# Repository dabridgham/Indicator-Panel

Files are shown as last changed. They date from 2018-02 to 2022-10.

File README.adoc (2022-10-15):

= Indicator Panel

Here we replicate the functionality of DEC's indicator panels used on
PDP-11s and some other machines.  It was designed in conjunction with
the http://github.com/dabridgham/QSIC[QSIC project] to build a QBUS
board to emulate the old DEC disk drives using more modern storage
technology and we wanted to have blinkenlights to go with.

indicator-panel*:: KiCad design for the indicator panel circuit boards
   themselves.  Three boards make a full indicator panel.

adapter*:: A small adapter board to convert from the version 1 pinout
   to version 2.

inlay*:: Various inlay designs we've come up with to use with the
   QSIC.
   * inlay-qbus: QBUS monitor.
   * inlay-rk11-c: Our idea of what the RK11-C indicator panel might
     have looked like.
   * inlay-rk11-f: Used for both the RK11-F and the RP11-D, the new
      controllers we've created for the QSIC.
   * inlay-rp11: The RP11 indicator panel rendered here.
   * inlay-unibus: Unibus monitor.

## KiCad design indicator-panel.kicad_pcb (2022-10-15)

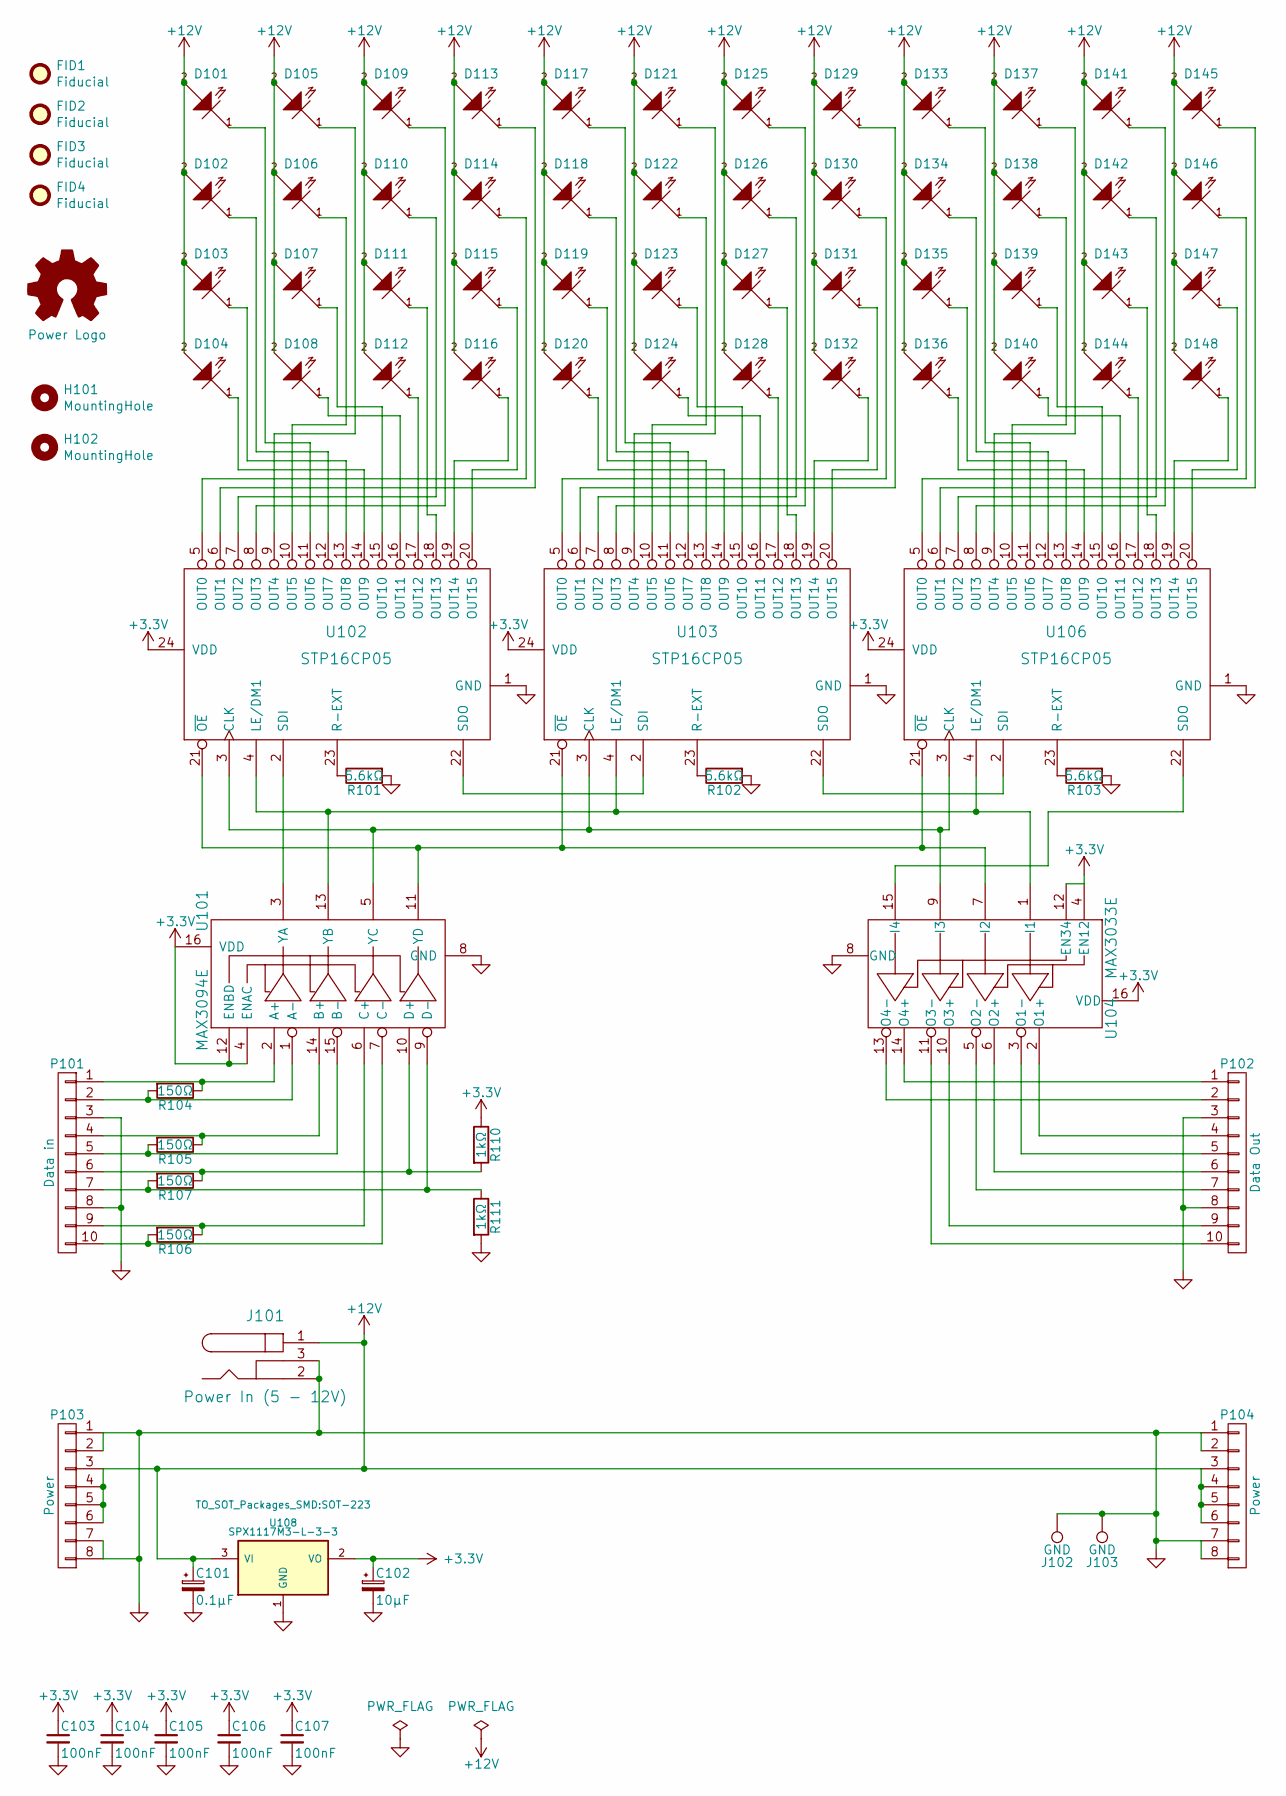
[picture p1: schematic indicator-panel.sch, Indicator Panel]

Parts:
C101: 0.1μF; CP_Tantalum_Case-R_EIA-2012-12_Reflow
C102: 10μF; CP_Tantalum_Case-R_EIA-2012-12_Wave
C103, C104, C105, C106, C107: 100nF; C_0805
D101, D102, D103, D104, D105, D106, D107, D108, D109, D110, D111, D112, D113, D114, D115, D116, D117, D118, D119, D120, D121, D122, D123, D124, D125, D126, D127, D128, D129, D130, D131, D132, D133, D134, D135, D136, D137, D138, D139, D140, D141, D142, D143, D144, D145, D146, D147, D148: LED-45; LED-0805
FID1, FID2, FID3, FID4: Fiducial; Fiducial_1mm_Mask2mm
H101, H102: MountingHole; MountingHole_3.5mm
J101: Power In (5 - 12V); PJ-032B
J102, J103: GND; MountingHole_3-5mm
P101: Data in; Pin_Header_Angled_2x05
P102: Data Out; Socket_Strip_Angled_2x05
P103: Power; Pin_Header_Angled_2x04
P104: Power; Socket_Strip_Angled_2x04
PowerLogo1: Power Logo; Barrel
R101, R102, R103: 5.6kΩ; R_0805
R104, R105, R106, R107: 150Ω; R_0805
R110, R111: 1kΩ; R_0805
U101: MAX3094E; SOIC-16_3.9x9.9mm_Pitch1.27mm
U102, U103, U106: STP16CP05; SOIC-24_7.5x15.4mm_Pitch1.27mm
U104: MAX3033E; SOIC-16_3.9x9.9mm_Pitch1.27mm
U108: SPX1117M3-L-3-3; SOT-223

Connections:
+3V3: C102.1, C103.1, C104.1, C105.1, C106.1, C107.1, R110.1, U101.4 (ENAC), U101.12 (ENBD), U101.16 (VDD), U102.24 (VDD), U103.24 (VDD), U104.4 (EN12), U104.12 (EN34), U104.16 (VDD), U106.24 (VDD), U108.2 (VO)
+12V: C101.1, D101.2 (A), D102.2 (A), D103.2 (A), D104.2 (A), D105.2 (A), D106.2 (A), D107.2 (A), D108.2 (A), D109.2 (A), D110.2 (A), D111.2 (A), D112.2 (A), D113.2 (A), D114.2 (A), D115.2 (A), D116.2 (A), D117.2 (A), D118.2 (A), D119.2 (A), D120.2 (A), D121.2 (A), D122.2 (A), D123.2 (A), D124.2 (A), D125.2 (A), D126.2 (A), D127.2 (A), D128.2 (A), D129.2 (A), D130.2 (A), D131.2 (A), D132.2 (A), D133.2 (A), D134.2 (A), D135.2 (A), D136.2 (A), D137.2 (A), D138.2 (A), D139.2 (A), D140.2 (A), D141.2 (A), D142.2 (A), D143.2 (A), D144.2 (A), D145.2 (A), D146.2 (A), D147.2 (A), D148.2 (A), J101.1, P103.3, P103.4, P103.5, P103.6, P104.3, P104.4, P104.5, P104.6, U108.3 (VI)
GND: C101.2, C102.2, C103.2, C104.2, C105.2, C106.2, C107.2, J101.2, J101.3, J102.1, J103.1, P101.3, P101.8, P102.3, P102.8, P103.1, P103.2, P103.7, P103.8, P104.1, P104.2, P104.7, P104.8, R101.2, R102.2, R103.2, R111.2, U101.8 (GND), U102.1 (GND), U103.1 (GND), U104.8 (GND), U106.1 (GND), U108.1 (GND)
unnamed: D101.1 (K), U102.11 (OUT6)
unnamed: D102.1 (K), U102.12 (OUT7)
unnamed: D103.1 (K), U102.13 (OUT8)
unnamed: D104.1 (K), U102.14 (OUT9)
unnamed: D105.1 (K), U102.9 (OUT4)
unnamed: D106.1 (K), U102.10 (OUT5)
unnamed: D107.1 (K), U102.15 (OUT10)
unnamed: D108.1 (K), U102.16 (OUT11)
unnamed: D109.1 (K), U102.8 (OUT3)
unnamed: D110.1 (K), U102.7 (OUT2)
unnamed: D111.1 (K), U102.18 (OUT13)
unnamed: D112.1 (K), U102.17 (OUT12)
unnamed: D113.1 (K), U102.6 (OUT1)
unnamed: D114.1 (K), U102.5 (OUT0)
unnamed: D115.1 (K), U102.20 (OUT15)
unnamed: D116.1 (K), U102.19 (OUT14)
unnamed: D117.1 (K), U103.11 (OUT6)
unnamed: D118.1 (K), U103.12 (OUT7)
unnamed: D119.1 (K), U103.13 (OUT8)
unnamed: D120.1 (K), U103.14 (OUT9)
unnamed: D121.1 (K), U103.9 (OUT4)
unnamed: D122.1 (K), U103.10 (OUT5)
unnamed: D123.1 (K), U103.15 (OUT10)
unnamed: D124.1 (K), U103.16 (OUT11)
unnamed: D125.1 (K), U103.8 (OUT3)
unnamed: D126.1 (K), U103.7 (OUT2)
unnamed: D127.1 (K), U103.18 (OUT13)
unnamed: D128.1 (K), U103.17 (OUT12)
unnamed: D129.1 (K), U103.6 (OUT1)
unnamed: D130.1 (K), U103.5 (OUT0)
unnamed: D131.1 (K), U103.20 (OUT15)
unnamed: D132.1 (K), U103.19 (OUT14)
unnamed: D133.1 (K), U106.11 (OUT6)
unnamed: D134.1 (K), U106.12 (OUT7)
unnamed: D135.1 (K), U106.13 (OUT8)
unnamed: D136.1 (K), U106.14 (OUT9)
unnamed: D137.1 (K), U106.9 (OUT4)
unnamed: D138.1 (K), U106.10 (OUT5)
unnamed: D139.1 (K), U106.15 (OUT10)
unnamed: D140.1 (K), U106.16 (OUT11)
unnamed: D141.1 (K), U106.8 (OUT3)
unnamed: D142.1 (K), U106.7 (OUT2)
unnamed: D143.1 (K), U106.18 (OUT13)
unnamed: D144.1 (K), U106.17 (OUT12)
unnamed: D145.1 (K), U106.6 (OUT1)
unnamed: D146.1 (K), U106.5 (OUT0)
unnamed: D147.1 (K), U106.20 (OUT15)
unnamed: D148.1 (K), U106.19 (OUT14)
unnamed: P101.1, R104.1, U101.2 (A+)
unnamed: P101.2, R104.2, U101.1 (A-)
unnamed: P101.4, R105.1, U101.14 (B+)
unnamed: P101.5, R105.2, U101.15 (B-)
unnamed: P101.6, R107.1, R110.2, U101.10 (D+)
unnamed: P101.7, R107.2, R111.1, U101.9 (D-)
unnamed: P101.9, R106.1, U101.6 (C+)
unnamed: P101.10, R106.2, U101.7 (C-)
unnamed: P102.1, U104.14 (O4+)
unnamed: P102.2, U104.13 (O4-)
unnamed: P102.4, U104.2 (O1+)
unnamed: P102.5, U104.3 (O1-)
unnamed: P102.6, U104.6 (O2+)
unnamed: P102.7, U104.5 (O2-)
unnamed: P102.9, U104.10 (O3+)
unnamed: P102.10, U104.11 (O3-)
unnamed: R101.1, U102.23 (R-EXT)
unnamed: R102.1, U103.23 (R-EXT)
unnamed: R103.1, U106.23 (R-EXT)
unnamed: U101.3 (YA), U102.2 (SDI)
unnamed: U101.5 (YC), U102.3 (CLK), U103.3 (CLK), U104.9 (I3), U106.3 (CLK)
unnamed: U101.11 (YD), U102.21 (~OE), U103.21 (~OE), U104.7 (I2), U106.21 (~OE)
unnamed: U101.13 (YB), U102.4 (LE/DM1), U103.4 (LE/DM1), U104.1 (I1), U106.4 (LE/DM1)
unnamed: U102.22 (SDO), U103.2 (SDI)
unnamed: U103.22 (SDO), U106.2 (SDI)
unnamed: U104.15 (I4), U106.22 (SDO)

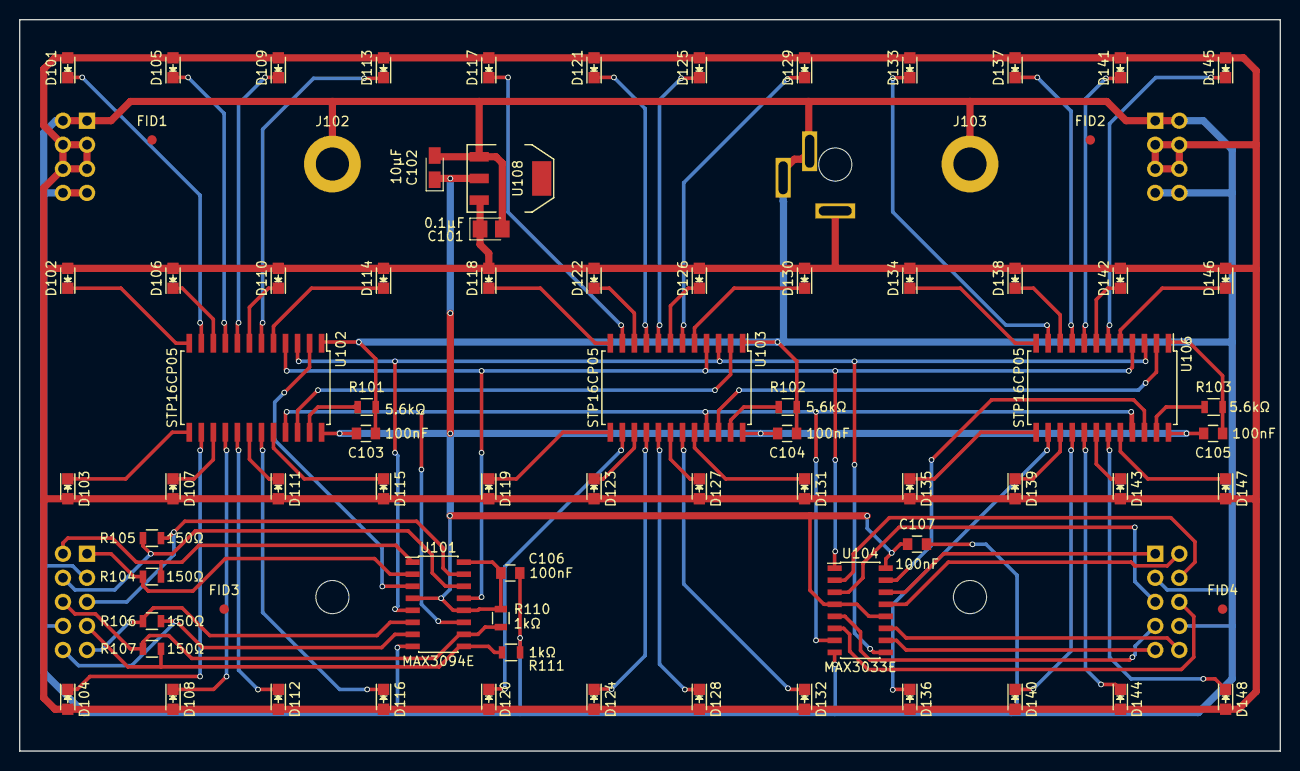
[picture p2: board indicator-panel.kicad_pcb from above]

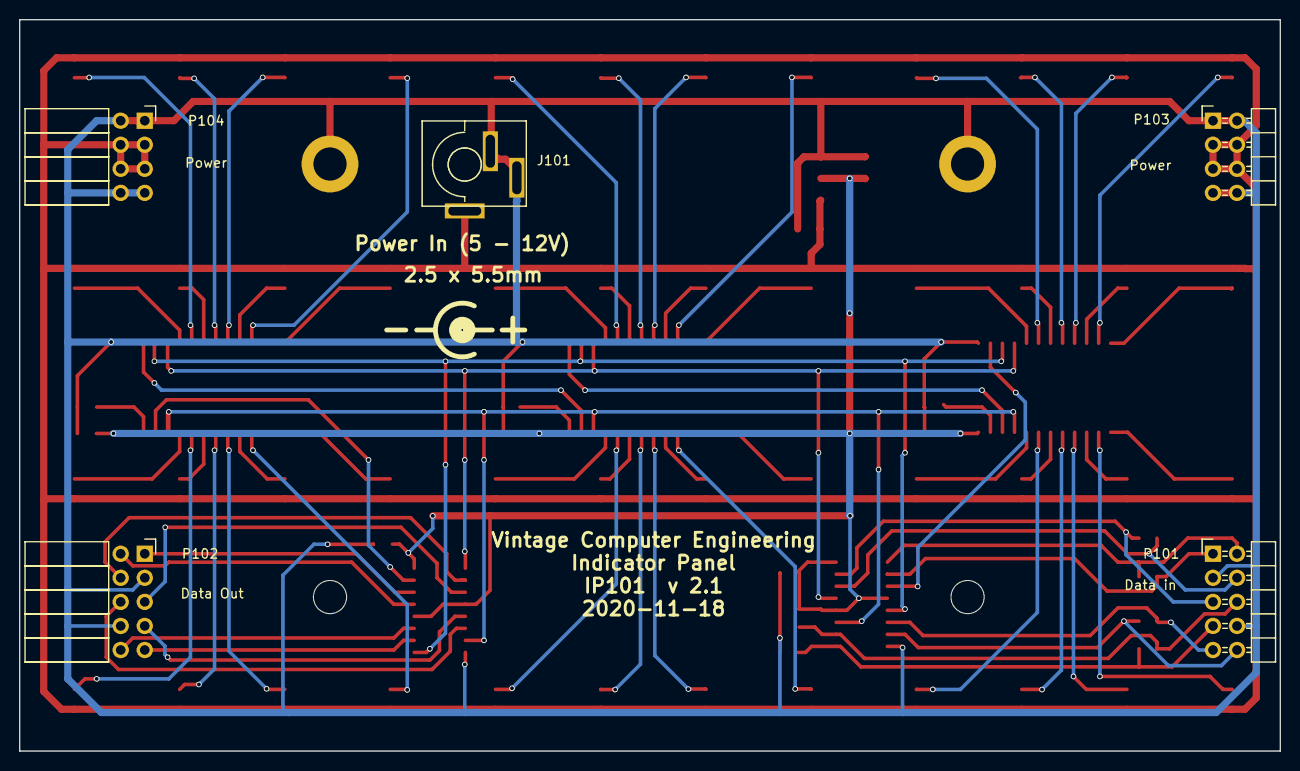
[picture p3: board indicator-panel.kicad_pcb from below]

Board: 2 copper layers, 133.1 x 77.2 mm, 84 parts (6 on the bottom side), 77 nets.

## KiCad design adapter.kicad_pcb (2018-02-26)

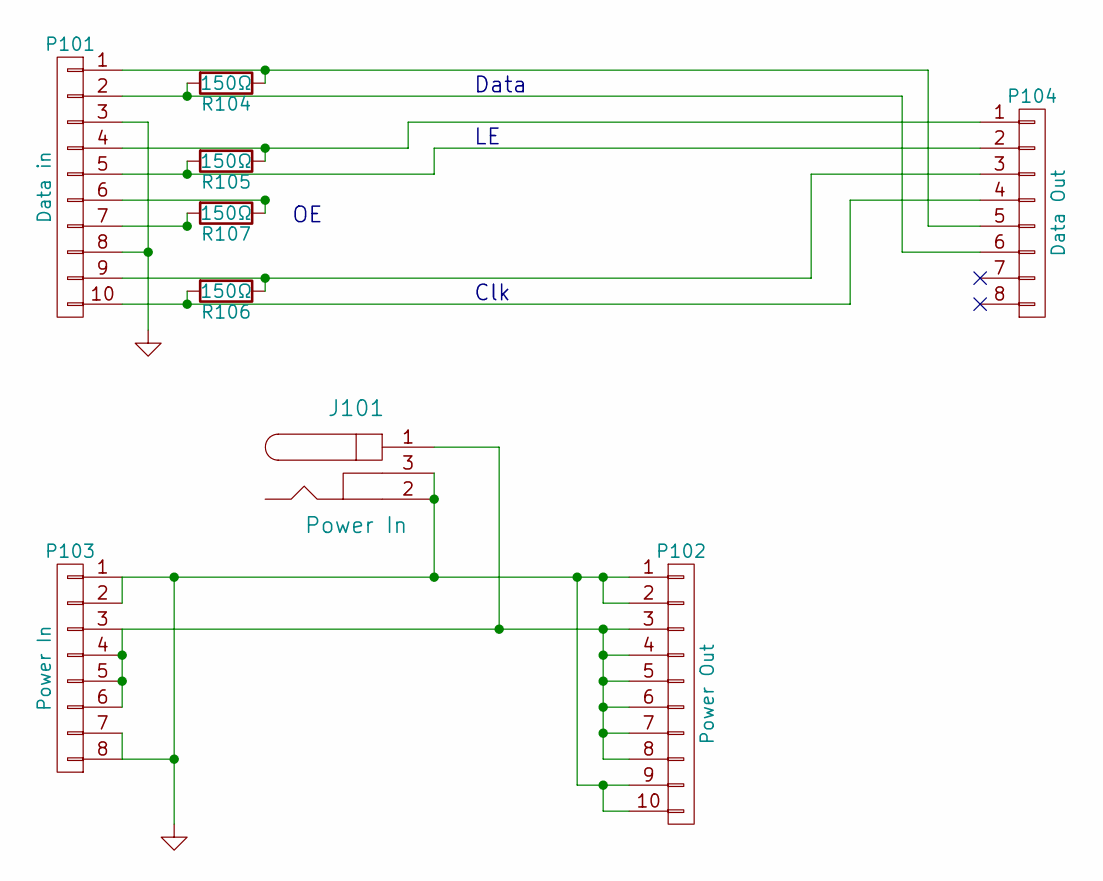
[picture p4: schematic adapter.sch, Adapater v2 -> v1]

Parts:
J101: Power In; PJ-032B
P101: Data in; Pin_Header_Straight_2x05
P102: Power Out; Socket_Strip_Straight_2x05
P103: Power In; Pin_Header_Straight_2x04
P104: Data Out; Socket_Strip_Straight_2x04
R104, R105, R106, R107: 150Ω; R_0805

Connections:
GND: J101.2, J101.3, P101.3, P101.8, P102.1, P102.2, P102.9, P102.10, P103.1, P103.2, P103.7, P103.8
unnamed: J101.1, P102.3, P102.4, P102.5, P102.6, P102.7, P102.8, P103.3, P103.4, P103.5, P103.6
unnamed: P101.1, P104.5, R104.1
unnamed: P101.2, P104.6, R104.2
unnamed: P101.4, P104.1, R105.1
unnamed: P101.5, P104.2, R105.2
unnamed: P101.6, R107.1
unnamed: P101.7, R107.2
unnamed: P101.9, P104.3, R106.1
unnamed: P101.10, P104.4, R106.2

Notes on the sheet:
Data
Clk

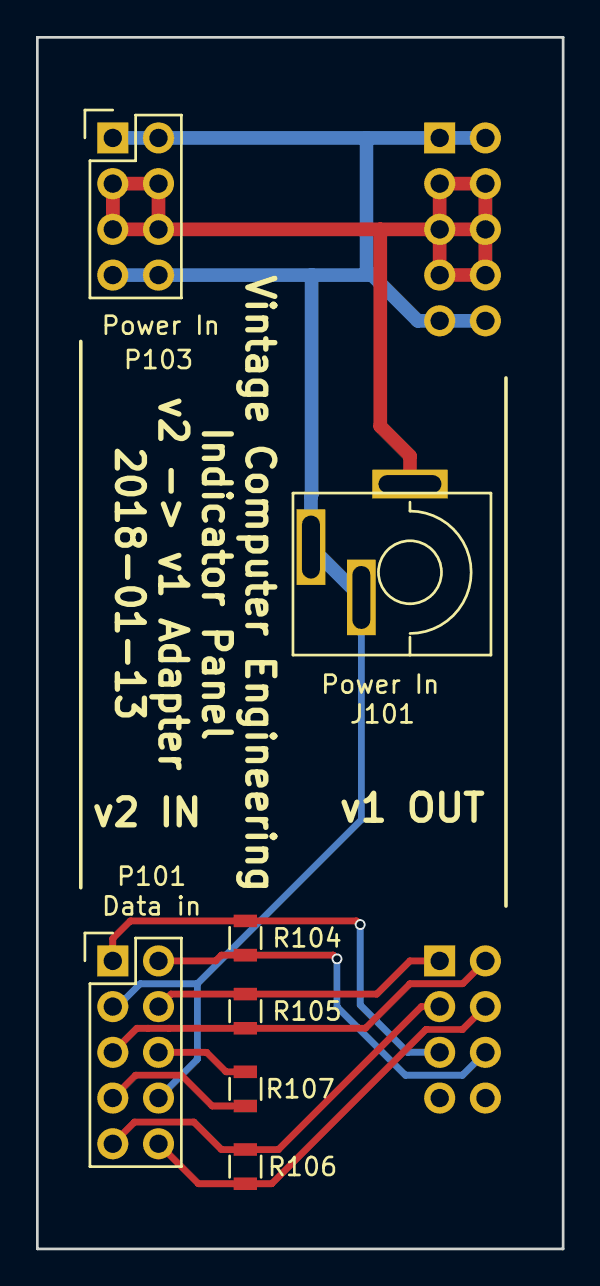
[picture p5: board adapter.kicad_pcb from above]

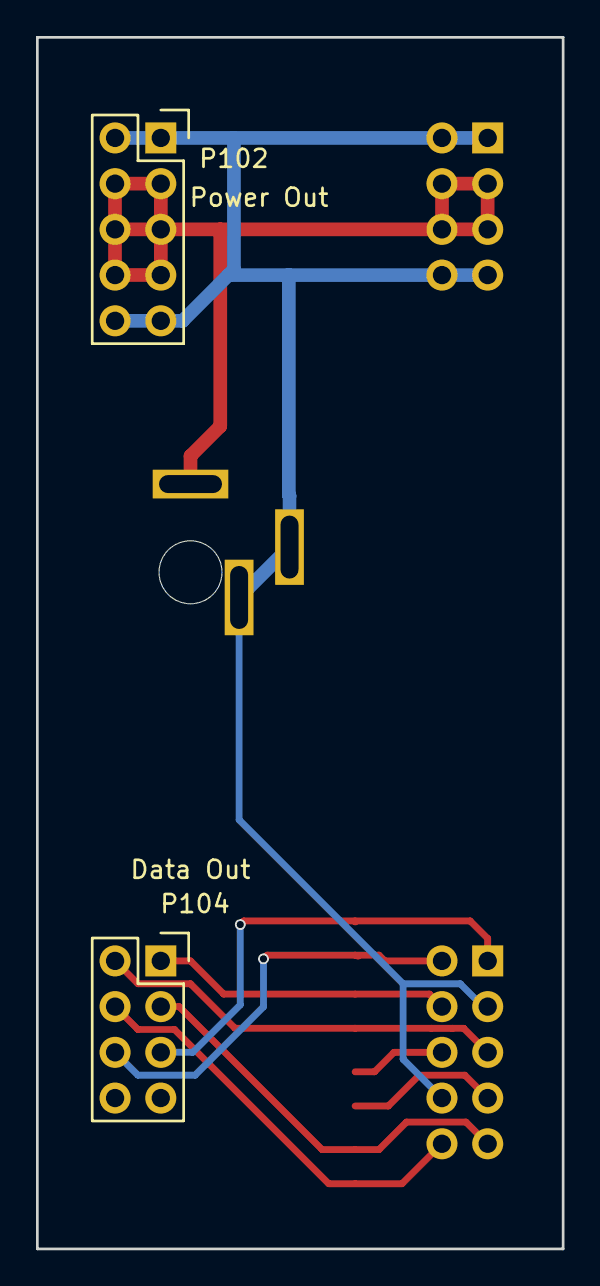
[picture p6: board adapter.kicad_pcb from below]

Board: 2 copper layers, 29.2 x 67.3 mm, 9 parts (2 on the bottom side), 10 nets.

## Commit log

2015-10-12 Renamed lights to indicator-panel.
    [indicator-panel.kicad_pcb, indicator-panel.sch]
2015-10-12 Added the simple mechanical drawing for the indicator panel.
    [mechanical.scad]
2015-10-14 Fix up connectors to carry current.
    [indicator-panel.kicad_pcb, indicator-panel.sch]
2015-10-27 Cleaned up schematic and added RK inlay.
    [indicator-panel.kicad_pcb, indicator-panel.sch]
2015-11-11 Updated pcb and rk11 inlay to .44x.88 spacing.
    [indicator-panel.kicad_pcb, indicator-panel.sch]
2015-12-21 Changed data connector use so it can be reversed with no harm. Updated version to 1.1.
    [indicator-panel.kicad_pcb, indicator-panel.sch]
2016-01-14 Added barrel connector.
    [indicator-panel.kicad_pcb, indicator-panel.sch]
2016-02-20 Added barrel connector and shrunk schematic to Letter size. Last update before changing to add Blank and Board Detect signals.
    [indicator-panel.kicad_pcb, indicator-panel.sch]
2016-02-23 Changed to version 2.0 with the blanking signal and using a 4-unit rs485 receiver and transmitter.
    [indicator-panel.kicad_pcb, indicator-panel.sch]
2017-01-29 Updated current limiting resistor to 3.3k
    [indicator-panel.kicad_pcb, indicator-panel.sch, mechanical.scad]
2017-04-16 switched over to asciidoc
2017-11-23 Fix for correct spacing
    [indicator-panel.kicad_pcb]
2017-11-23 Line up connectors
    [indicator-panel.sch]
2017-11-26 Moved mounting holes to give a better attach point in the light shield
    [indicator-panel.kicad_pcb]
2017-11-26 Make VDD and GND pins on chips visible.
    [indicator-panel.kicad_pcb, indicator-panel.sch]
2017-12-04 Relocated coaxial power connector and increased pad size on its footprint.
    [indicator-panel.kicad_pcb]
2017-12-26 Added fiducials and ground pads
    [indicator-panel.kicad_pcb]
2018-01-14 Changed current limiting resistor to 8.2k
    [indicator-panel.kicad_pcb, indicator-panel.sch]
2018-02-01 Touch up some dates.
    [indicator-panel.kicad_pcb, indicator-panel.sch]
2018-02-26 Finalized v2 signal layout and submitted first batch for production.
    [adapter.kicad_pcb, adapter.sch, indicator-panel.kicad_pcb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]
2018-03-28 Changed the tantalum capacitor footprint to more clearly show the positive end. Added some text around the power connector on the back.
    [indicator-panel.kicad_pcb, indicator-panel.sch]
2018-11-26 Update to KiCad 5.0
    [indicator-panel.sch]
2019-01-07 Bring in the cache and rescue files too.
    [indicator-panel.sch]
2020-02-25 A first cut at a Unibus monitor panel
2021-12-04 Fix up the alignment and switch fonts. Also rename to rk11-c.
2021-12-04 Added fiducials
    [indicator-panel.sch]
2022-10-15 KiCAD changed the name of its .pro file.
